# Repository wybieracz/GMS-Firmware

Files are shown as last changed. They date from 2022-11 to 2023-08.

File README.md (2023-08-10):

# Grid Management System - Device and Firmware
## IoT class system of electricity management based on a cloud interface
The project involves the design and development of a device that allows remote control the power supply of the connected receiver. Powering the receiver on and off should be possible on demand, after a certain period of time, during designated periods. In addition, the device will conduct measurements of voltage and current and count the energy used (Smart Socket). The second part of the project is creation of a web application to manage the device and present statistics. Communication with the device and data storage will be possible through a configured cloud service.
## Technologies
* C++
* Azure IoT Hub
* Azure Stream Analytics
* ESP-32
## Libraries
* SPIFFS
* LiquidCrystal
* ESPAsyncWebServer
* EmonLib
* Azure IoT device SDK for C
## Device features
* Wi-Fi connection wizzard
* 230V/10A power supply control
* Manual mode, time mode, auto mode
* Programmable display (Voltage and current, date, power, power consumption)
* Power compsumption counter with auto-resetter
* Sending telemetry to cloud
## Circuit idea diagram
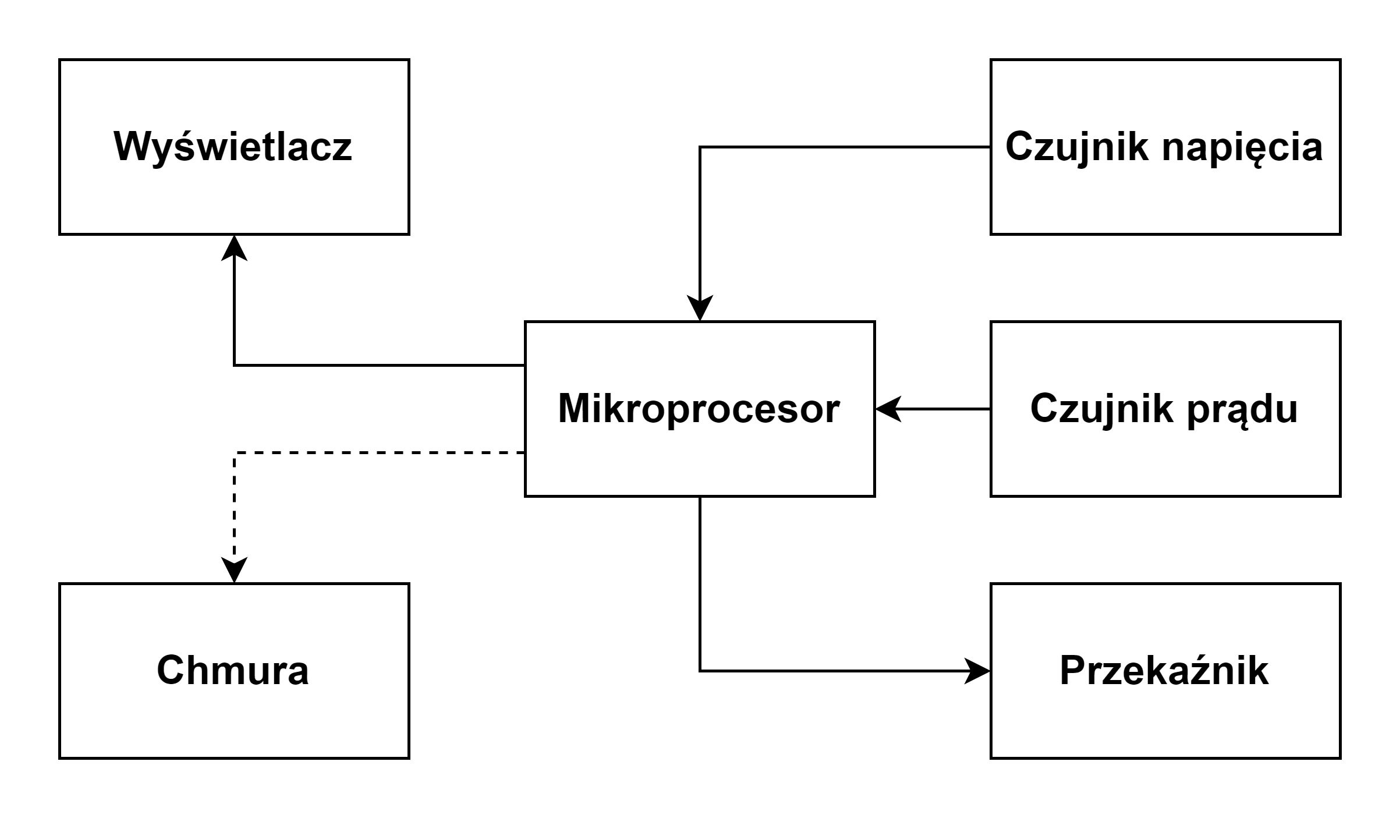
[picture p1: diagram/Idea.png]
idea

## Circuit diagram
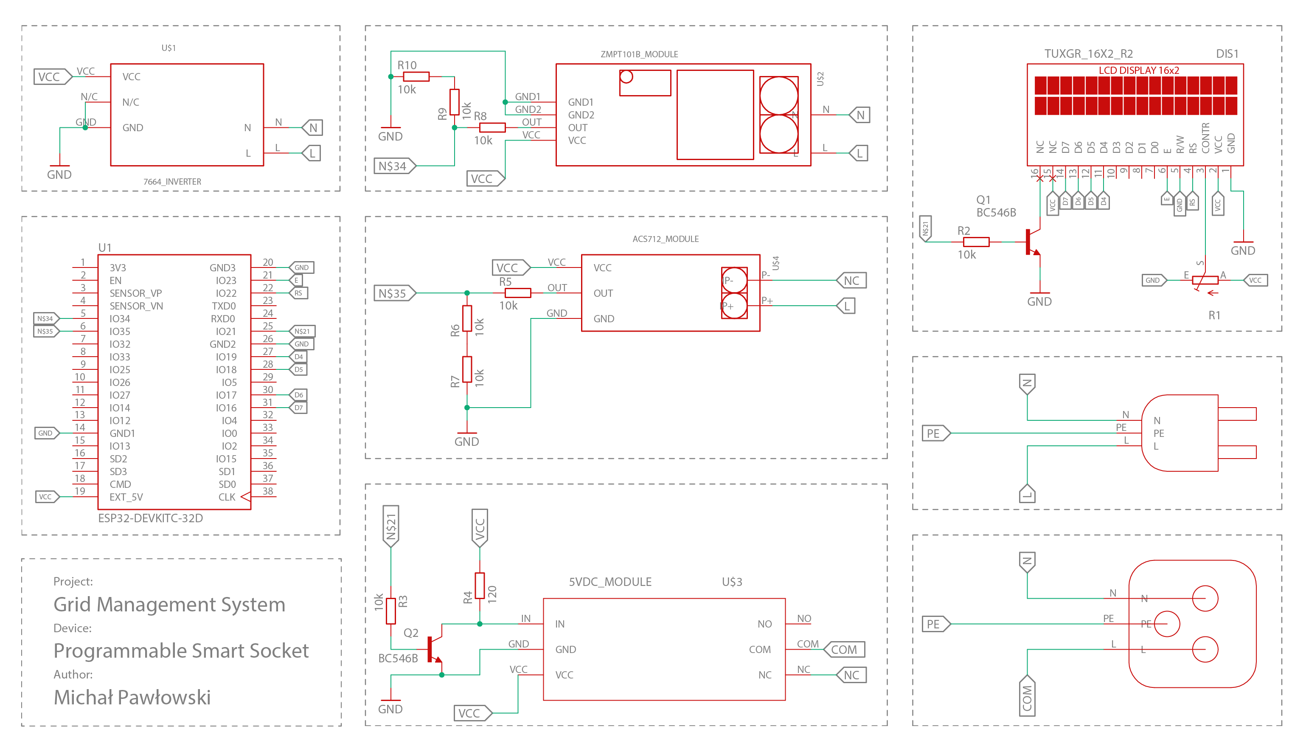
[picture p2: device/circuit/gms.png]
circuit

## PCB design
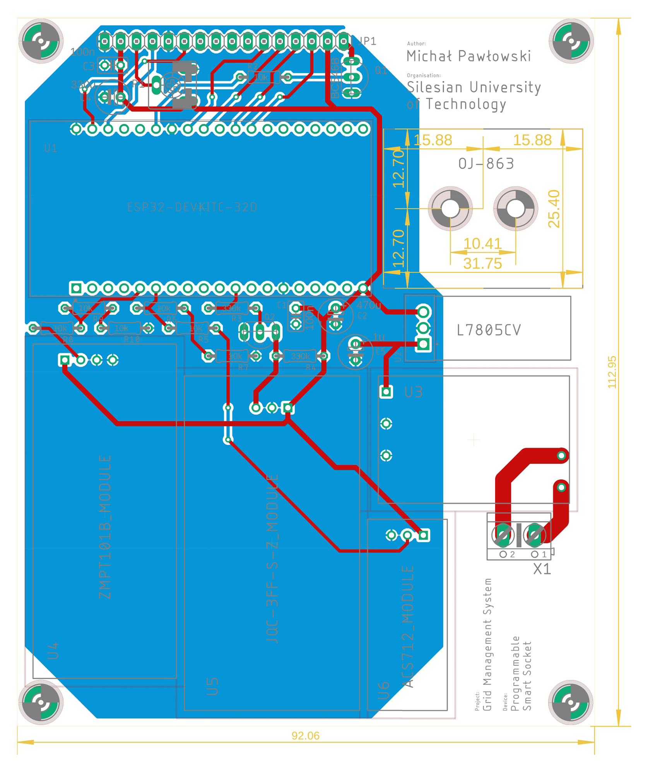
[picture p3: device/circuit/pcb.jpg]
pcb

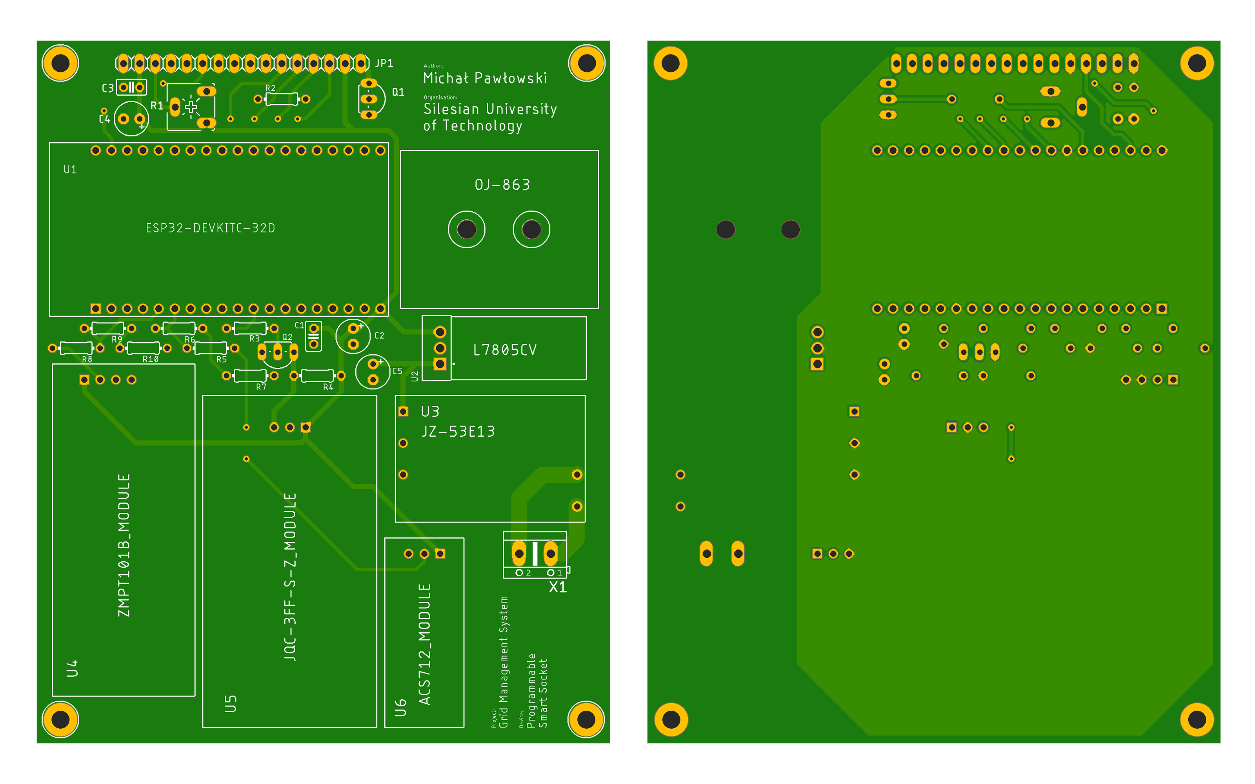
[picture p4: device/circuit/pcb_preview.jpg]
pcb_preview

## Device case design
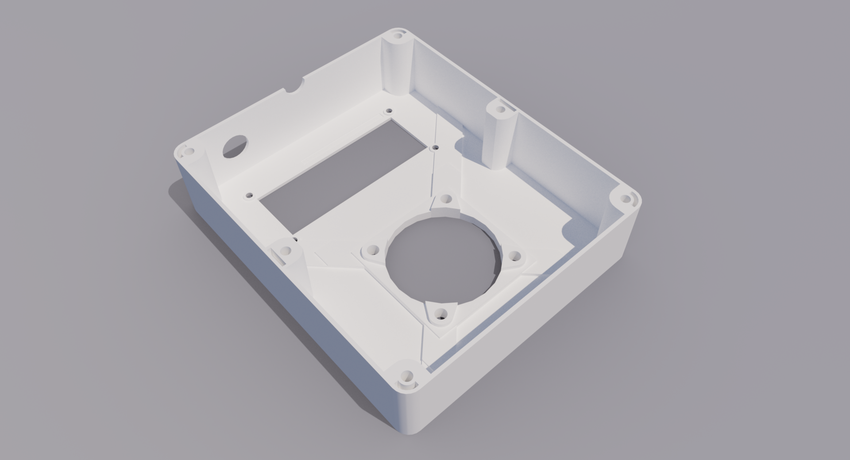
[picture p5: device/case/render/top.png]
case_top

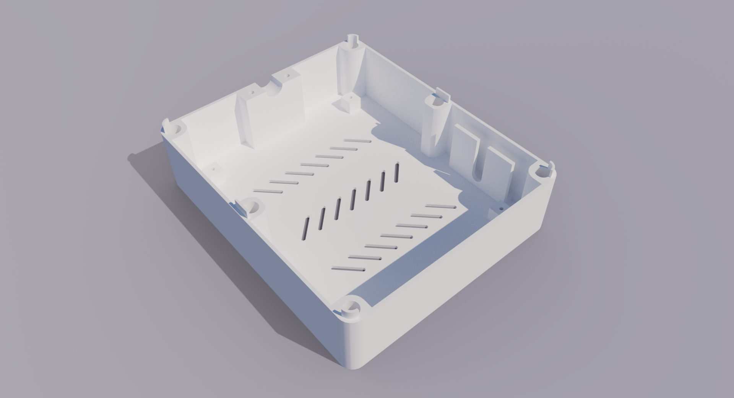
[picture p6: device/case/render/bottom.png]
case_bottom

## System architecture
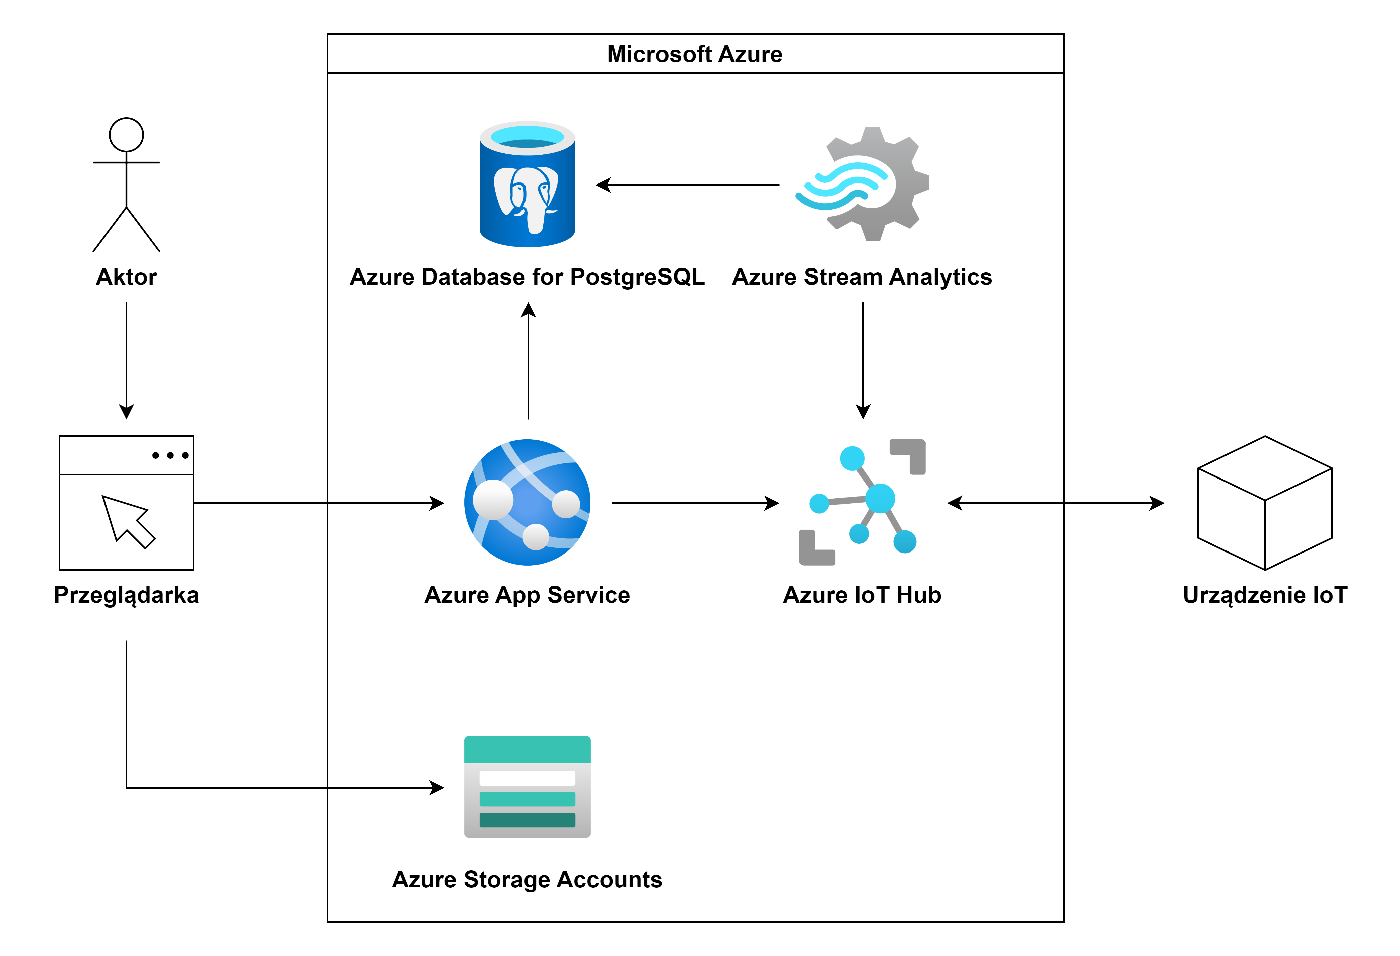
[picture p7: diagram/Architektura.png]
architecture

The solution consists of six major components:
* IoT Device - smart device able to work in GMS.
* Azure IoT Hub - a managed cloud service that acts as a central message hub for communication between an IoT application and its attached devices.
* Azure Stream Analytics - cloud service that provides real-time analytic computations on the data streaming from IoT devices.
* Azure Database for PostgreSQL - Database used to store devices telemetry and web app data.
* Azure App Service - Web app used for device manipulation and telemetry presentation. [(Backend)](https://github.com/wybieracz/GMS-App)
* Azure Storage Accounts - Web app used for device manipulation and telemetry presentation. [(Frontend)](https://github.com/wybieracz/GMS-App)
## Getting started
1. Create IoT device using circuit diagram / PCB design.
2. Create account on [Microsoft Azure](https://azure.microsoft.com/en-gb/).
3. Create [Azure IoT Hub](https://docs.microsoft.com/en-gb/azure/iot-hub/iot-hub-create-through-portal).
4. In Azure IoT Hub add new device via `Devices > Add Device`.
5. Clone repository.
6. Open `AzIoTConfig.h` file.
* In Azure IoT Hub open `Overview` to show hostname.
* Enter cloud hostname `IOTHUB_FQDN`.
* In Azure IoT Hub open `Devices > Your Device Name` to show cloud device credentials.
* Enter cloud device credentials, Device ID `DEVICE_ID` and Primary Key `DEVICE_KEY`.
7. Build and upload programme to ESP-32.
8. Create Postgres database.
9. Run [backend](https://github.com/wybieracz/GMS-App) to create entities.
10. Add manually data about devices into devices table.
11. Create and configure Azure Stream Analytics.
* Define Azure IoT Hub as an input in `Inputs > Add input`.
* Define Postgres database as an output in `Outputs > Add output`.
* Define query:
```
SELECT
    [deviceId],
    [voltage],
    [current],
    [power],
    [kWh],
    [timestamp]
INTO
    [database_name]
FROM
    [iot_hub_name]
```
12. Connect power supply to device.
13. Connect to the Wi-Fi network. Credentials will be displayed on device display.
14. Go to `192.168.4.1` and pass credentials to your home Wi-Fi. The device will reboot and connect to the Wi-Fi.
15. Your device is now online and can be linked with your account.
16. For device manipulation check [GMS - App](https://github.com/wybieracz/SZEE-App).
## Device
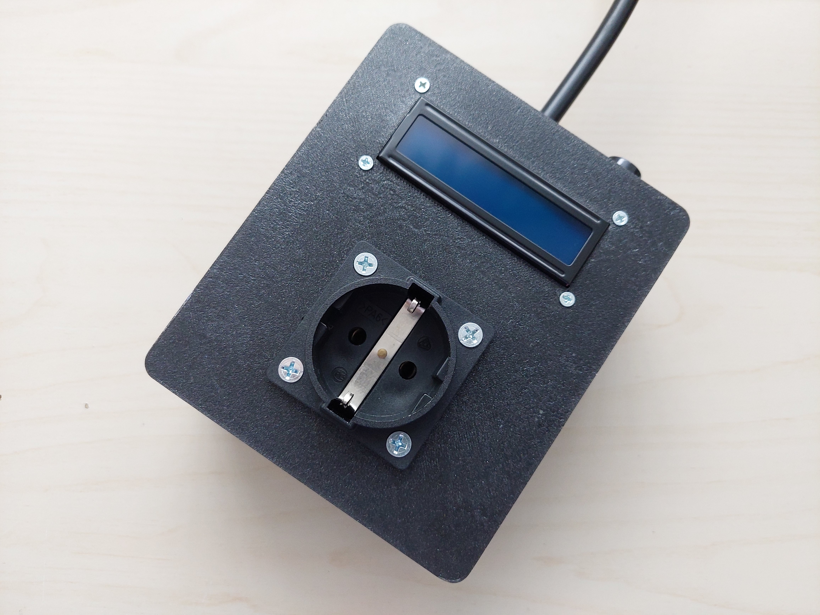
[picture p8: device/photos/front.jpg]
device_front

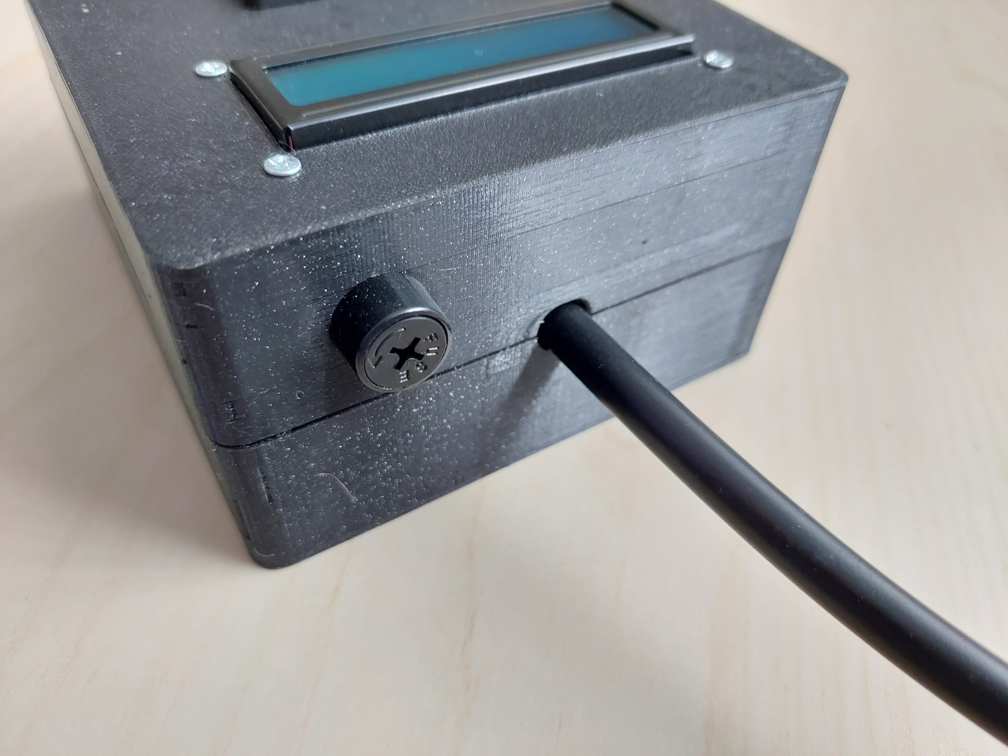
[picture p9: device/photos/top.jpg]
device_top

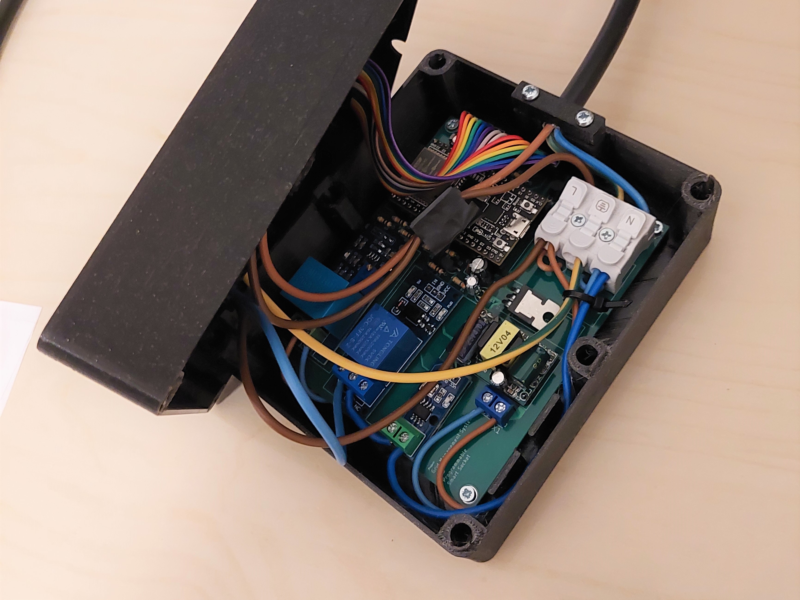
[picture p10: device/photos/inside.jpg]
device_inside

Device overview.

device_wifi
After device startup it will show Wi-Fi credentials. When connected, it is possible to configure device netowrk settings and connect it to the home Wi-Fi.

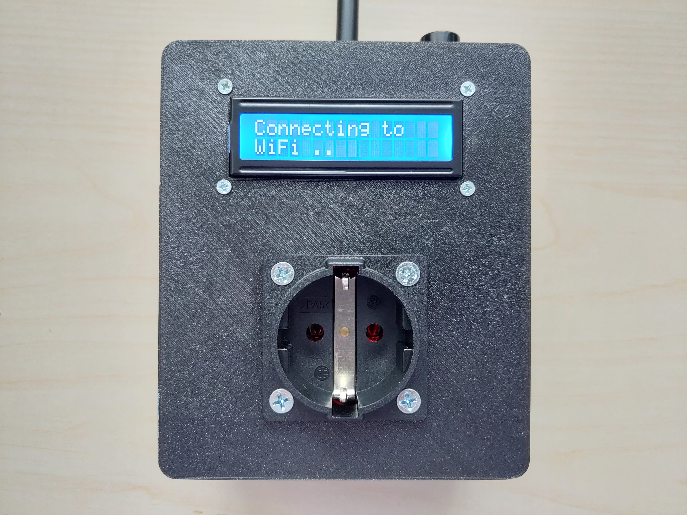
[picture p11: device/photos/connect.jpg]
device_connect

After network configuration, device will reboot and connect to the home Wi-Fi.

device_display_1
device_display_2
It is possible to configure data presented on device display. 16x2 LCD allows to display two of data: Time and date, voltage and current, power, power comsumption. In addition it is powwible to change display brightness.
## Video presentation
[YouTube](https://youtu.be/LqCKxmR3ckY)

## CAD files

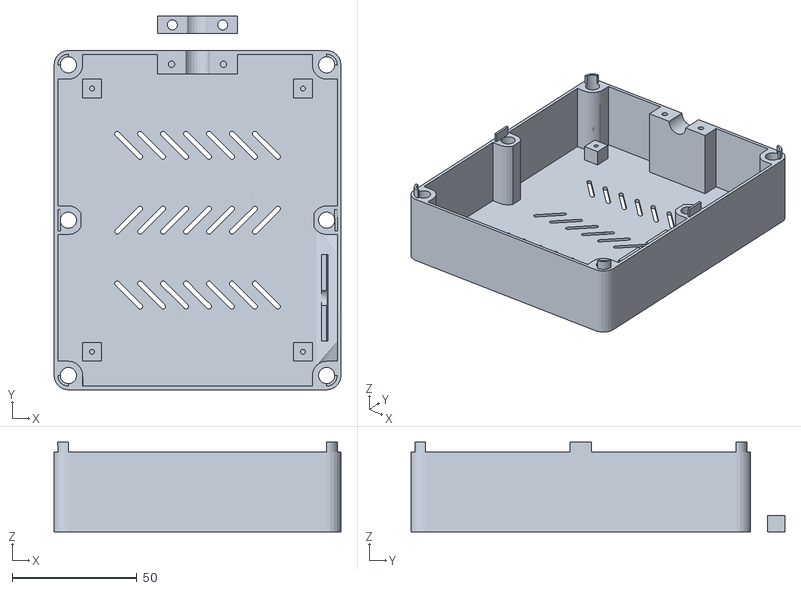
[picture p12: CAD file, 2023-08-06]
device/case/bottom.stl
115.0 x 149.8 x 36.0

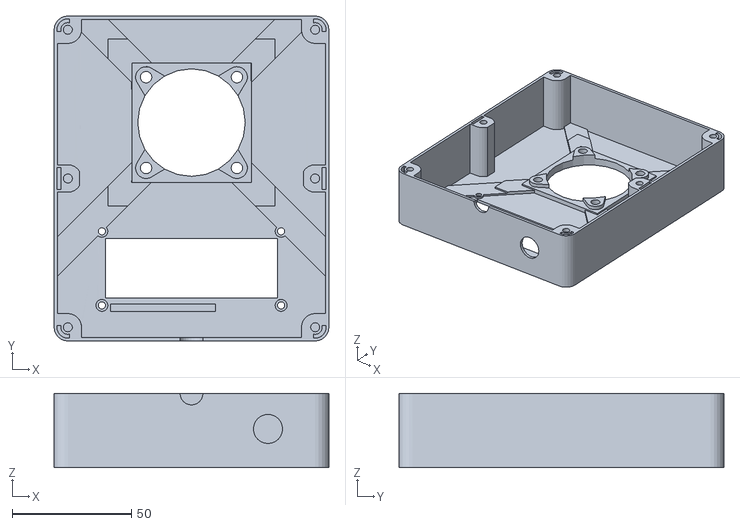
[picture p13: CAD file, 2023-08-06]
device/case/top.stl
115.0 x 136.0 x 31.0

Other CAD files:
device/case/bottom.skp
device/case/top.skp

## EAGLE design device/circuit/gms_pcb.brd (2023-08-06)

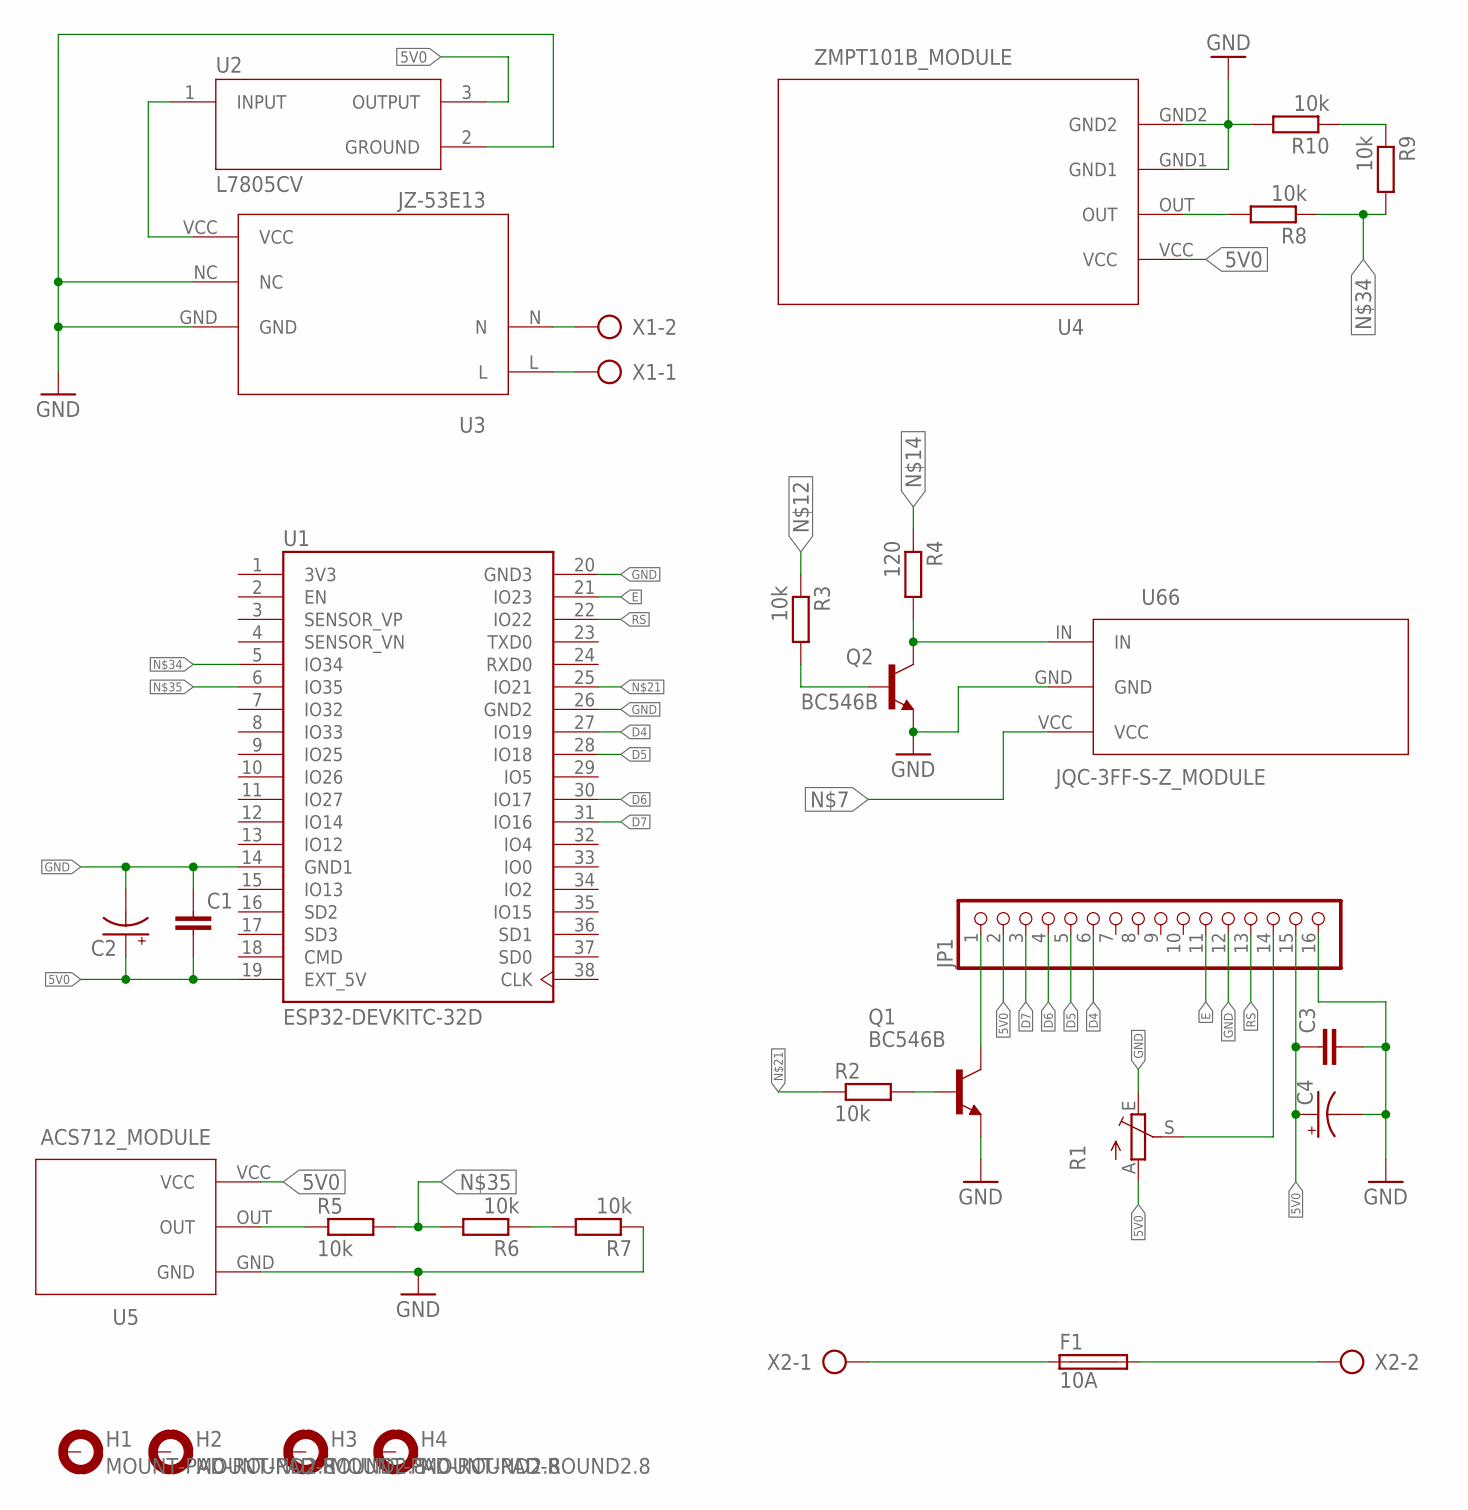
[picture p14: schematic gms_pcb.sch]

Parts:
C1, C3: C-EU025-025X050; C025-025X050
C2, C4: CPOL-USE2.5-6; E2,5-6
F1: 10A; SH25
H1, H2, H3, H4: MOUNT-PAD-ROUND2.8; 2,8-PAD
JP1: PINHD-1X16; 1X16
Q1, Q2: BC546B; TO92-EBC
R1: TRIM_EU-CA6V; CA6V
R2, R3, R5, R6, R7, R8, R9, R10: 10k; 0204/7
R4: 120; 0204/7
U1: ESP32-DEVKITC-32D; MODULE_ESP32-DEVKITC-32D
U2: L7805CV; TO255P1040X460X1968-3
U3: JZ-53E13
U4: ZMPT101B_MODULE
U5: ACS712_MODULE
U66: JQC-3FF-S-Z_MODULE; JQC-3FF-S-Z_MOUDLE
X1, X2: AK500/2

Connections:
3V3: U1.1 (3V3)
5V0: C1.2, C2.+, C3.1, C4.+, JP1.2, JP1.15, R1.A, U1.19 (EXT_5V), U2.3 (OUTPUT), U4.VCC, U5.VCC
12V0: U2.1 (INPUT), U3.VCC
D4: JP1.6, U1.27 (IO19)
D5: JP1.5, U1.28 (IO18)
D6: JP1.4, U1.30 (IO17)
D7: JP1.3, U1.31 (IO16)
E: JP1.11, U1.21 (IO23)
GND: C1.1, C2.-, C3.2, C4.-, JP1.12, JP1.16, Q1.E, Q2.E, R1.E, R7.1, R10.2, U1.14 (GND1), U1.20 (GND3), U1.26 (GND2), U2.2 (GROUND), U3.GND, U3.NC, U4.GND1, U4.GND2, U5.GND, U66.GND
L2: F1.1, X2.1
N2: F1.2, X2.2
unnamed: Q2.C, R4.2, U66.IN
unnamed: JP1.14, R1.S
unnamed: R8.2, U4.OUT
unnamed: U3.N, X1.2
unnamed: JP1.1, Q1.C
unnamed: Q1.B, R2.2
unnamed: Q2.B, R3.2
unnamed: R9.1, R10.1
unnamed: R6.1, R7.2
unnamed: U3.L, X1.1
unnamed: R5.1, U5.OUT
unnamed: R2.1, U1.25 (IO21)
unnamed: R8.1, R9.2, U1.5 (IO34)
unnamed: R5.2, R6.2, U1.6 (IO35)
RS: JP1.13, U1.22 (IO22)

Board: 2 copper layers, 30 parts (0 on the bottom side), 25 nets, no tracks yet.

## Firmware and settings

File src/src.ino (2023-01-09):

#include <Arduino.h>
#include "TimeManager.h"
#include "WiFiManager.h"
#include "AzIoTClient.h"
#include "EnergyManager.h"

void setup() {
  initPinout();
  flashManager.init();
  lcdManager.init();
  relayManager.init();
  energyManager.init();

  if(wifiManager.init()) {
    timeManager.init();
    iotClient.init();
    digitalWrite(LED_GREEN, HIGH);
  } else {
    wifiManager.setAP();
  }
}

void loop() {
  if (!wifiManager.isAPActive()) {
    if (WiFi.status() != WL_CONNECTED) {
      digitalWrite(LED_RED, LOW);
      if(!wifiManager.init()) wifiManager.setAP();
    }
    else {
      iotClient.check();
      energyManager.calc(20, 1000);
      energyManager.print();
      energyManager.display();
      relayManager.checkRules();
    }
  } 
}

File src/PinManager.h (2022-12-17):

#ifndef PINMANAGER_H
#define PINMANAGER_H

#include <Arduino.h>

#define LED_RED 25
#define LED_BLUE 26
#define LED_GREEN 32
#define LED_YELLOW 33
#define RELAY 27
#define D7 16
#define D6 17
#define D5 18
#define D4 19
#define E 23
#define RS 22
#define LED_LCD 21
#define V_IN 34
#define I_IN 35

void initPinout();

#endif //PINMANAGER_H

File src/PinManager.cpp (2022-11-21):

#include "PinManager.h"

void initPinout() {
  pinMode(LED_RED, OUTPUT);
  pinMode(LED_BLUE, OUTPUT);
  pinMode(LED_GREEN, OUTPUT);
  pinMode(LED_YELLOW, OUTPUT);
  pinMode(RELAY, OUTPUT);
}

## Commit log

2022-11-21 feature: wifi manager, flash memory, relay, lcd
2022-11-29 feature: return device status
2022-12-07 fix: setRegistered fix and set rules if empty on boot
    [RelayManager.cpp]
2022-12-09 fix: payloadBuffer overflow fix
    [RelayManager.cpp]
2022-12-10 fix: auto mode in local time
    [RelayManager.cpp]
2022-12-22 fix: energy calculation fix
    [EnergyManager.cpp, EnergyManager.h, LcdManager.cpp]
2023-01-03 fix: unregister device fix
    [WiFiManager.cpp]
2023-01-09 fix: mothod handler function removal
    [src.ino]
2023-08-06 docs: add screenshots and photos
    [bottom.skp, bottom.stl, gms.sch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]
